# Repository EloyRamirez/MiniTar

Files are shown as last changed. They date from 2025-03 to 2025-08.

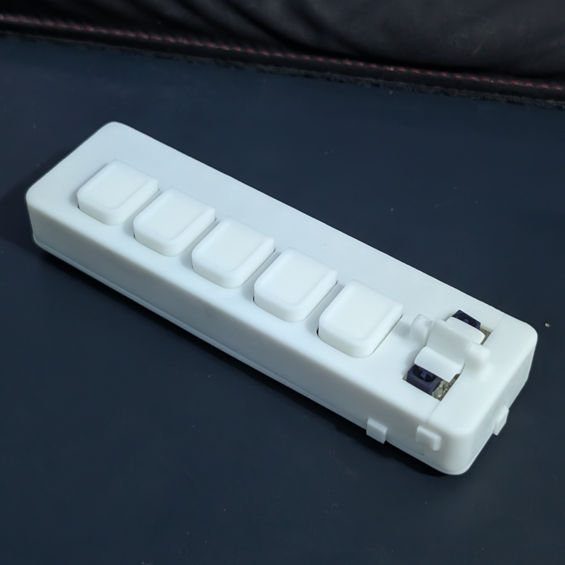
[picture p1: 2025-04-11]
images/MiniTar Final.jpg

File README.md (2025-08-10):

# MiniTar
Personal project to create smallest guitar hero controller.

I'm building a guitar hero (clone hero) controller with the bare minimum functions (frets and strum bar) and I'm trying to make it as small and compact as I can.
I'm using an RP2040 and followed the minimal hardware design doc from RasPi as reference. 
It's my first time designing a board just using components and no breakouts. 

Using JLCPCB for manufacturing and assembly of SMT components. DFM checks tailored to their requirements.
Soldering THT components myself.

Using the Santroller Configurator to program RP2040 firmware.

My reference for size is the Nintendo DS version of Guitar Hero which came with a controller attachment specifically for the Nintendo DS Lite that connects into the GBA port on the bottom to use the fret buttons. My goal being that the final product is less in volume than a Nintendo DS Lite 211,603mm^3.

The case was modeled in Fusion 360 with a final volume of 38,031mm^3.
Using JLC3DP for 3D printing.

Future plans: Add gyro and wammy bar.

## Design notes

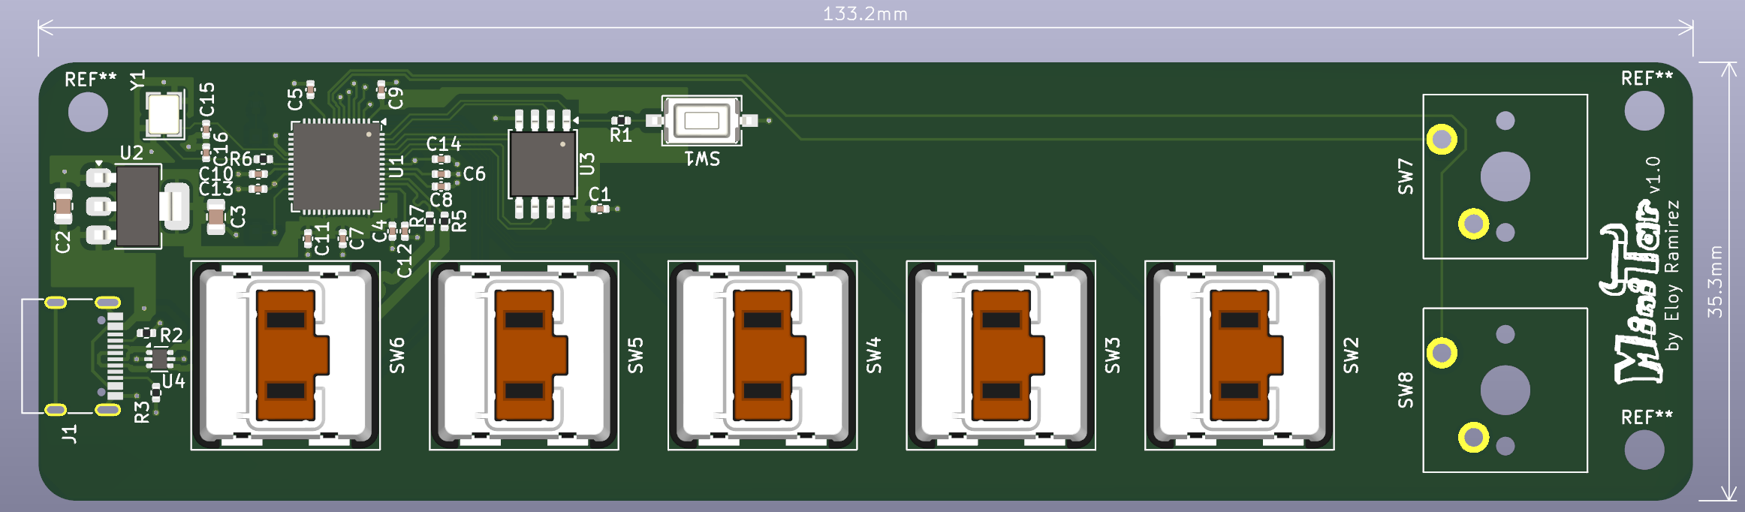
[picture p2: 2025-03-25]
images/5-3D Front.png

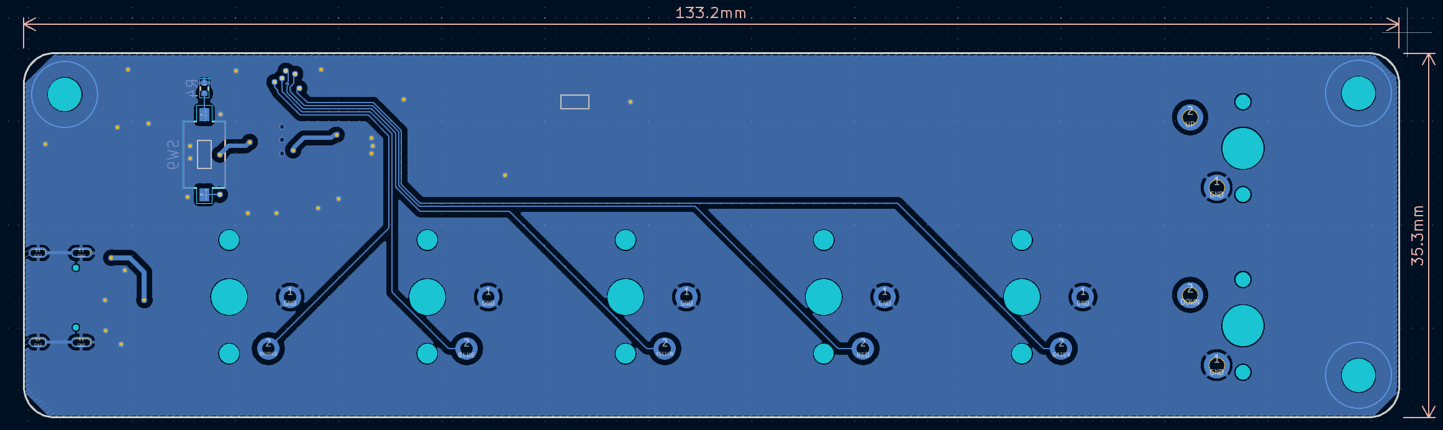
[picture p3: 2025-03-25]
images/4-Copper Backpng.png

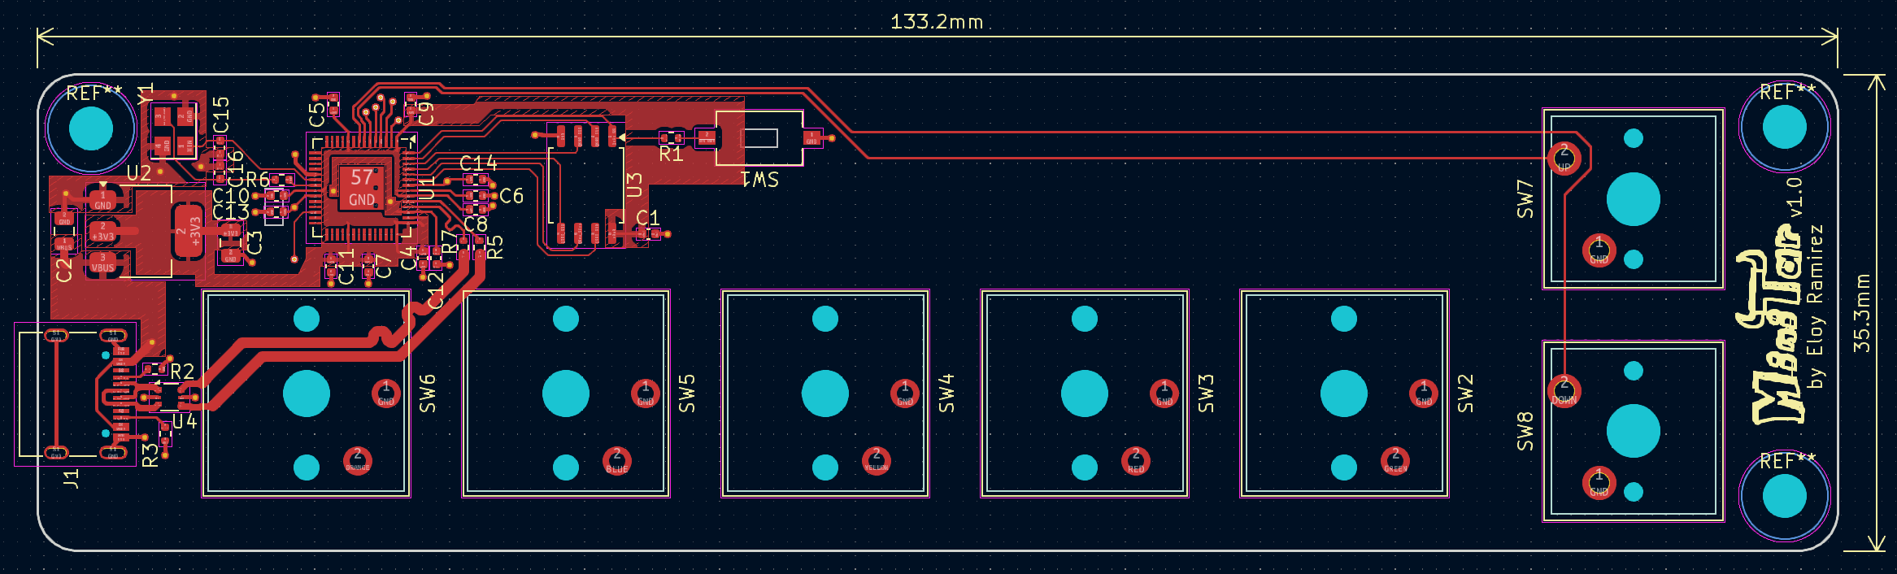
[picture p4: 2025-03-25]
images/2-Copper Front.png

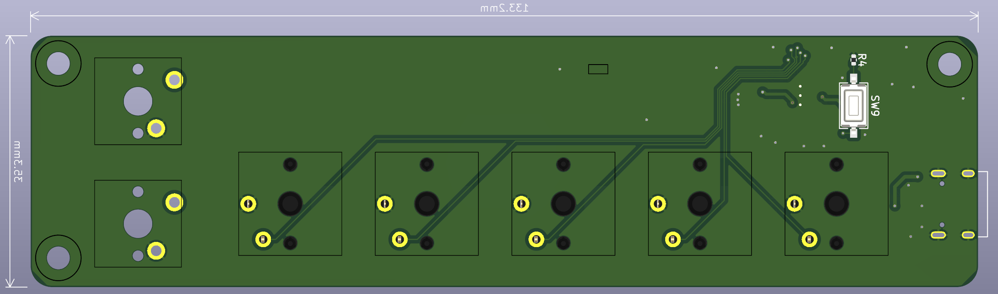
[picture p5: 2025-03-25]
images/6-3D Back.png

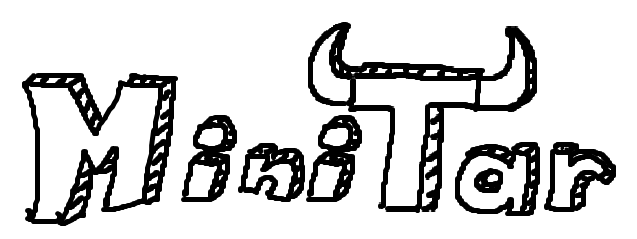
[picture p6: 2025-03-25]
images/MiniTar.png

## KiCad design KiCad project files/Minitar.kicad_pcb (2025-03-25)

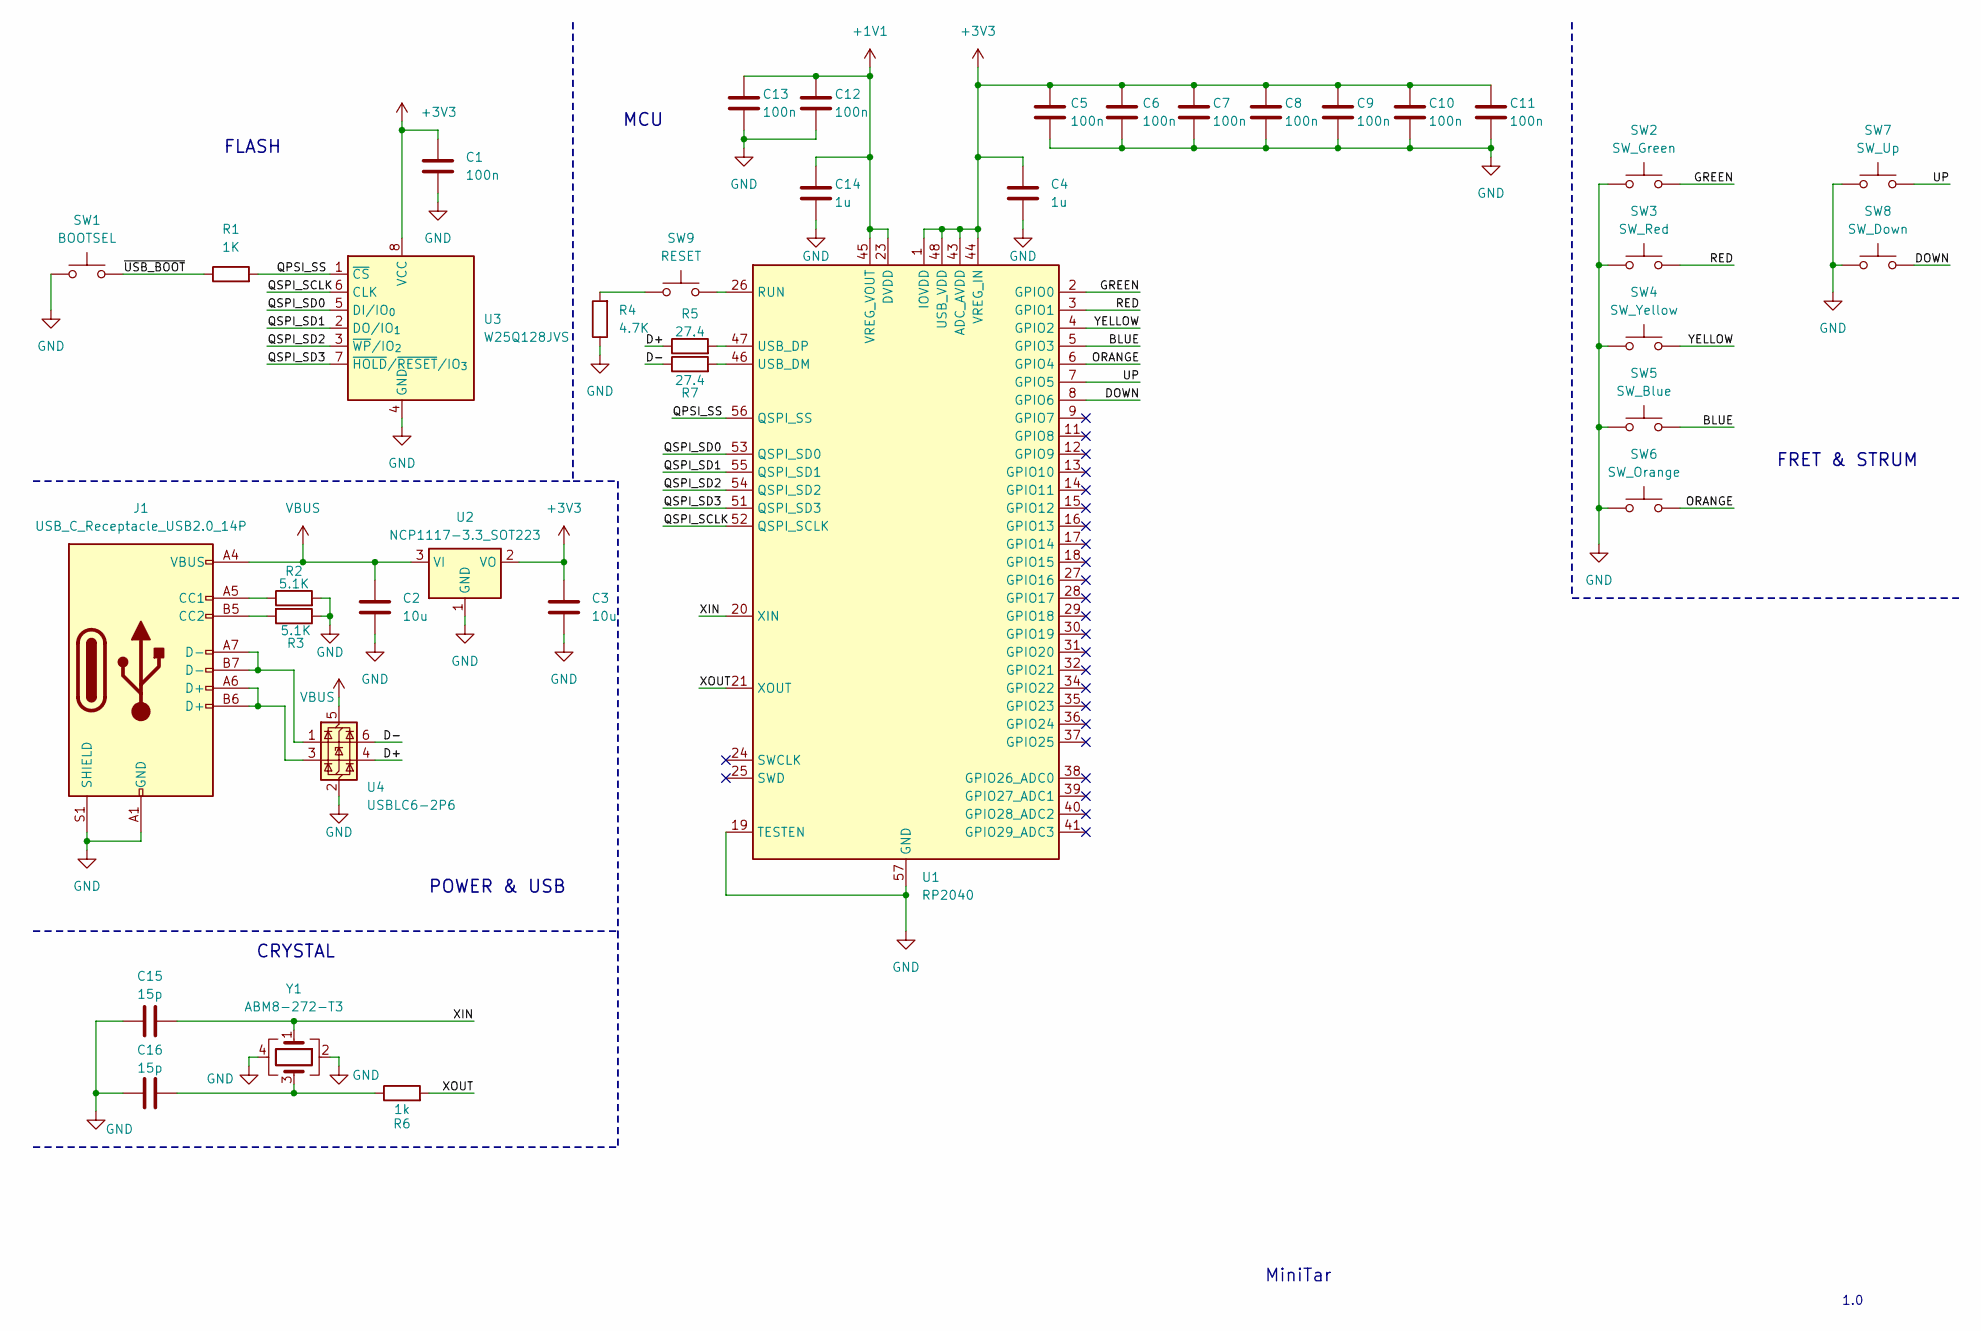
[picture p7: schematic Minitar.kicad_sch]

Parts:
C1, C5, C6, C7, C8, C9, C10, C11, C12, C13: 100n; C_0402_1005Metric
C2, C3: 10u; C_0805_2012Metric
C4, C14: 1u; C_0402_1005Metric
C15, C16: 15p; C_0402_1005Metric
J1: USB_C_Receptacle_USB2.0_14P; USB_C_Receptacle_G-Switch_GT-USB-7010ASV
R1: 1K; R_0402_1005Metric
R2, R3: 5.1K; R_0402_1005Metric
R4: 4.7K; R_0402_1005Metric
R5, R7: 27.4; R_0402_1005Metric
R6: 1k; R_0402_1005Metric
SW1: BOOTSEL; SW_Tactile_SPST_NO_Straight_CK_PTS636Sx25SMTRLFS
SW2: SW_Green; SW_Kailh_Choc_V1
SW3: SW_Red; SW_Kailh_Choc_V1
SW4: SW_Yellow; SW_Kailh_Choc_V1
SW5: SW_Blue; SW_Kailh_Choc_V1
SW6: SW_Orange; SW_Kailh_Choc_V1
SW7: SW_Up; SW_Kailh_KH
SW8: SW_Down; SW_Kailh_KH
SW9: RESET; SW_Tactile_SPST_NO_Straight_CK_PTS636Sx25SMTRLFS
U1: RP2040; QFN-56-1EP_7x7mm_P0.4mm_EP3.2x3.2mm
U2: NCP1117-3.3_SOT223; SOT-223-3_TabPin2
U3: W25Q128JVS; SOIC-8_5.3x5.3mm_P1.27mm
U4: USBLC6-2P6; SOT-666
Y1: ABM8-272-T3; Crystal_SMD_Abracon_ABM8G-4Pin_3.2x2.5mm

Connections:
+1V1: C12.1, C13.1, C14.1, U1.23 (DVDD), U1.45 (VREG_VOUT), U1.50 (DVDD)
+3V3: C1.1, C3.1, C4.1, C5.1, C6.1, C7.1, C8.1, C9.1, C10.1, C11.1, U1.1 (IOVDD), U1.10 (IOVDD), U1.22 (IOVDD), U1.33 (IOVDD), U1.42 (IOVDD), U1.43 (ADC_AVDD), U1.44 (VREG_IN), U1.48 (USB_VDD), U1.49 (IOVDD), U2.2 (VO), U3.8 (VCC)
/BLUE: SW5.2, U1.5 (GPIO3)
/D+: R5.1, U4.4 (I/O2)
/D-: R7.1, U4.6 (I/O1)
/DOWN: SW8.2, U1.8 (GPIO6)
/GREEN: SW2.2, U1.2 (GPIO0)
/ORANGE: SW6.2, U1.6 (GPIO4)
/QPSI_SS: R1.2, U1.56 (QSPI_SS), U3.1 (~CS)
/QSPI_SCLK: U1.52 (QSPI_SCLK), U3.6 (CLK)
/QSPI_SD0: U1.53 (QSPI_SD0), U3.5 (DI/IO_{0})
/QSPI_SD1: U1.55 (QSPI_SD1), U3.2 (DO/IO_{1})
/QSPI_SD2: U1.54 (QSPI_SD2), U3.3 (~WP/IO_{2})
/QSPI_SD3: U1.51 (QSPI_SD3), U3.7 (~HOLD/~RESET/IO_{3})
/RED: SW3.2, U1.3 (GPIO1)
/UP: SW7.2, U1.7 (GPIO5)
/XIN: C15.2, U1.20 (XIN), Y1.1
/XOUT: R6.2, U1.21 (XOUT)
/YELLOW: SW4.2, U1.4 (GPIO2)
/~USB_BOOT: R1.1, SW1.2
GND: C1.2, C2.2, C3.2, C4.2, C5.2, C6.2, C7.2, C8.2, C9.2, C10.2, C11.2, C12.2, C13.2, C14.2, C15.1, C16.1, J1.A1 (GND), J1.A12 (GND), J1.B1 (GND), J1.B12 (GND), J1.S1 (SHIELD), R2.2, R3.1, R4.1, SW1.1, SW2.1, SW3.1, SW4.1, SW5.1, SW6.1, SW7.1, SW8.1, U1.19 (TESTEN), U1.57 (GND), U2.1 (GND), U3.4 (GND), U4.2 (GND), Y1.2, Y1.4
unnamed: C16.2, R6.1, Y1.3
unnamed: J1.A5 (CC1), R2.1
unnamed: J1.B5 (CC2), R3.2
unnamed: J1.A6 (D+), J1.B6 (D+), U4.3 (I/O2)
unnamed: J1.A7 (D-), J1.B7 (D-), U4.1 (I/O1)
unnamed: R4.2, SW9.1
unnamed: SW9.2, U1.26 (RUN)
unnamed: R7.2, U1.46 (USB_DM)
unnamed: R5.2, U1.47 (USB_DP)
VBUS: C2.1, J1.A4 (VBUS), J1.A9 (VBUS), J1.B4 (VBUS), J1.B9 (VBUS), U2.3 (VI), U4.5 (VBUS)

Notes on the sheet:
FRET & STRUM
MiniTar
1.0
POWER & USB
FLASH
CRYSTAL
MCU

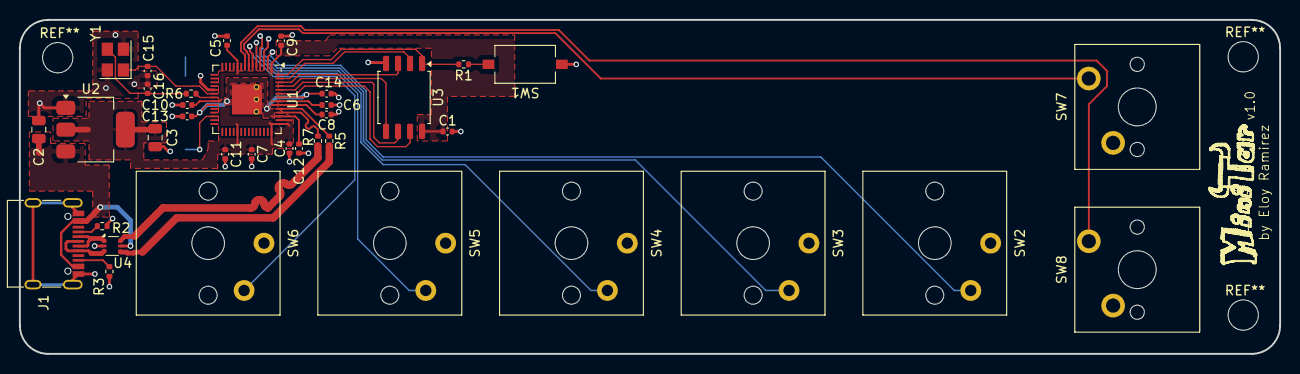
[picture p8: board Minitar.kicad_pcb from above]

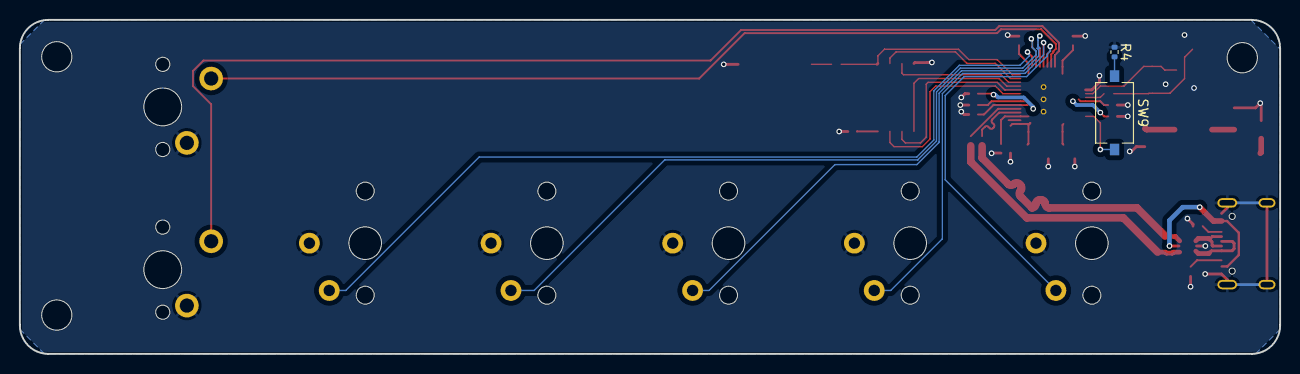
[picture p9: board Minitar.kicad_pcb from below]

Board: 2 copper layers, 133.2 x 35.3 mm, 38 parts (2 on the bottom side), 31 nets.

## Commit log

2025-03-25 Added KiCad project files
    [Minitar.kicad_pcb, Minitar.kicad_sch]
2025-04-03 Update README.md
    Added information on case and 3D printing
